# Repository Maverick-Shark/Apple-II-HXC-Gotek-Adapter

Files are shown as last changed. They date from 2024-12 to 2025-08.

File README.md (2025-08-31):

### Source

https://github.com/liveboxandy/Gotek-Rotary-Encoder

###  Description

Simple adapter PCB based on the wiring diagram from https://hxc2001.com/docs/gotek-floppy-emulator-hxc-firmware/pages/apple.html

### BOM

[Interactive BOM](https://djtersteegc.github.io/Apple-II-HXC-Gotek-Adapter/ibom.html)

| Item | Qty  | Notes | Link |
| --- | ---- | --- | --- |
| 2x17 34p 2.54mm Female Pin Socket | 1 | | [AliExpress](https://www.aliexpress.us/item/3256805948524386.html) |
| 2x10 20p 2.54mm IDC Male Box Header | 1 | | [AliExpress](https://www.aliexpress.us/item/3256807284267150.html) |
| 1x4 4p 2.54mm Female Pin Socket | 1 | | [AliExpress](https://www.aliexpress.us/item/2255800509919410.html) |
| Female Dupont Jumper Wires | 2 | From adapter to Gotek TX/RX headers | [AliExpress](https://www.aliexpress.us/item/3256807188673626.html) |
| 1x40 2.54mm Male Header | 1 | To populate Gotek header pins | [AliExpress](https://www.aliexpress.us/item/3256805949945647.html) |

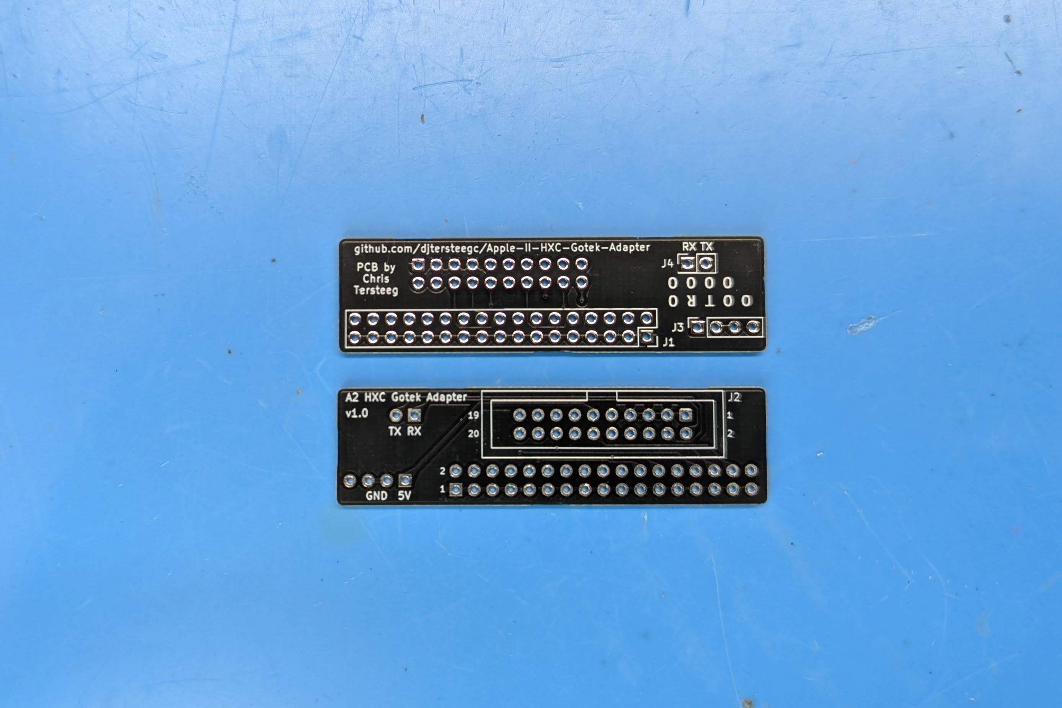
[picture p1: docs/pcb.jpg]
pcb


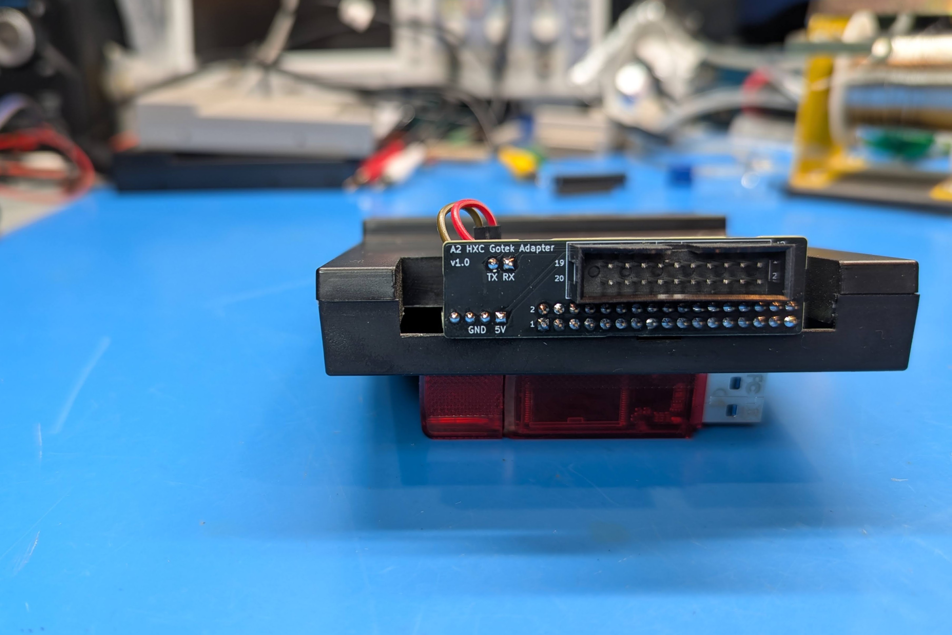
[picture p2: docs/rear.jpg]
rear


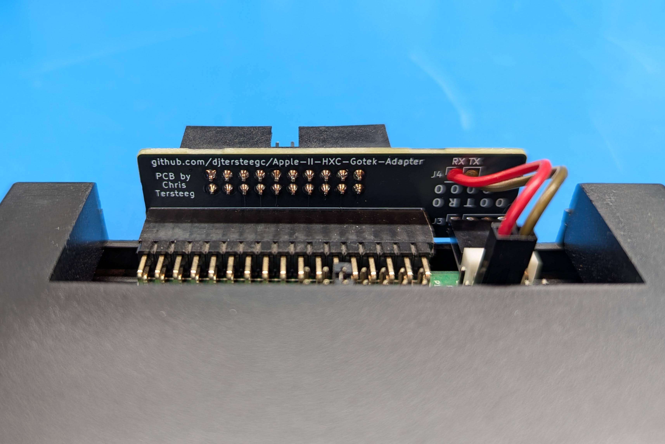
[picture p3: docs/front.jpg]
front


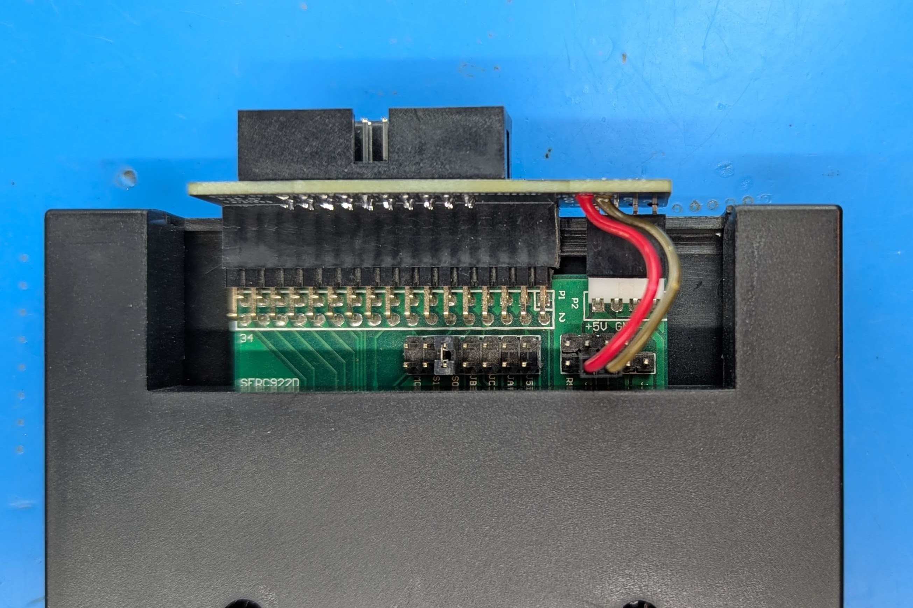
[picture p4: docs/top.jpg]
top


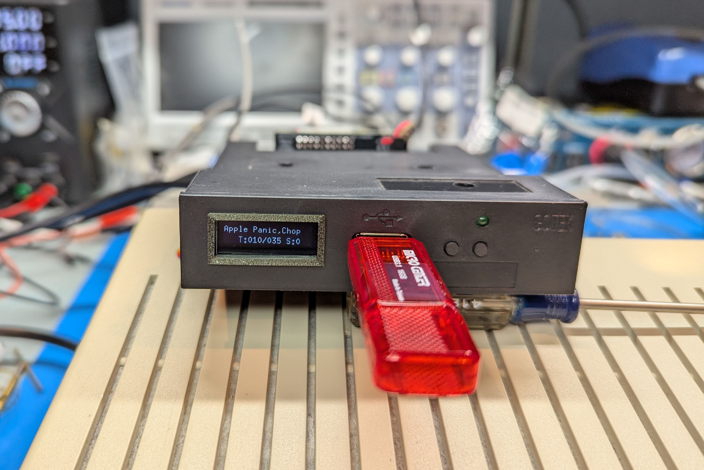
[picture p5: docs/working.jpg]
working


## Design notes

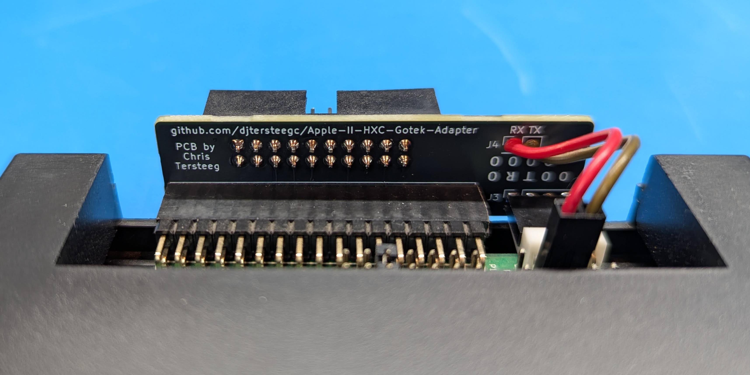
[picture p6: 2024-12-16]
docs/social.jpg

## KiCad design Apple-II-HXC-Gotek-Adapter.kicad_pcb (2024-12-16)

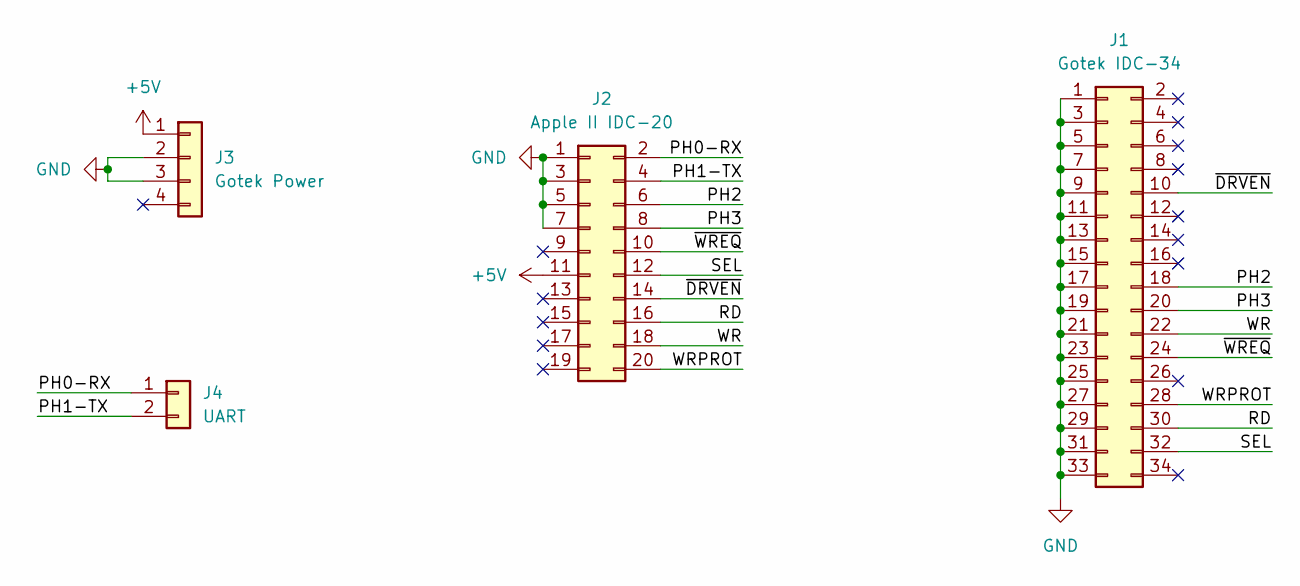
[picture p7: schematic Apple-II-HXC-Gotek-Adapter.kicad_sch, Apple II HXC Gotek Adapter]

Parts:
J1: Gotek IDC-34; PinSocket_2x17_P2.54mm_Vertical
J2: Apple II IDC-20; IDC-Header_2x10_P2.54mm_Vertical
J3: Gotek Power; PinSocket_1x04_P2.54mm_Vertical
J4: UART; PinHeader_2x01_P2.54mm_Vertical

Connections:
+5V: J2.11, J3.1
/PH0-RX: J2.2, J4.1
/PH1-TX: J2.4, J4.2
/PH2: J1.18, J2.6
/PH3: J1.20, J2.8
/RD: J1.30, J2.16
/SEL: J1.32, J2.12
/WR: J1.22, J2.18
/WRPROT: J1.28, J2.20
/~DRVEN: J1.10, J2.14
/~WREQ: J1.24, J2.10
GND: J1.1, J1.3, J1.5, J1.7, J1.9, J1.11, J1.13, J1.15, J1.17, J1.19, J1.21, J1.23, J1.25, J1.27, J1.29, J1.31, J1.33, J2.1, J2.3, J2.5, J2.7, J3.2, J3.3

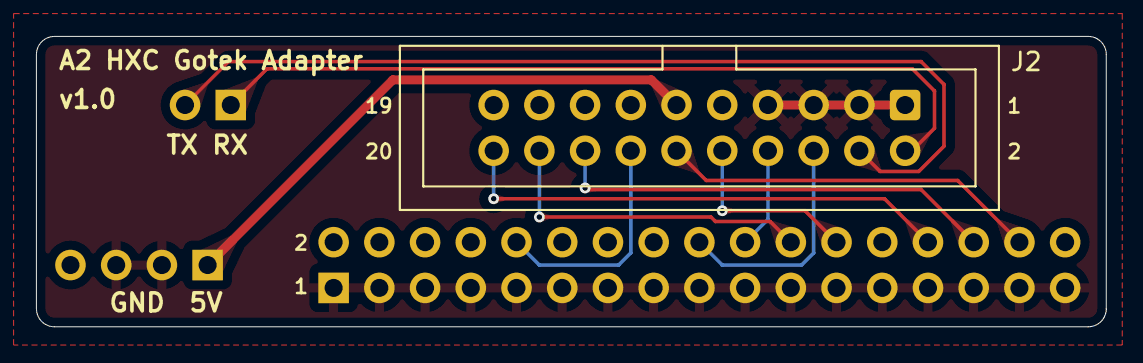
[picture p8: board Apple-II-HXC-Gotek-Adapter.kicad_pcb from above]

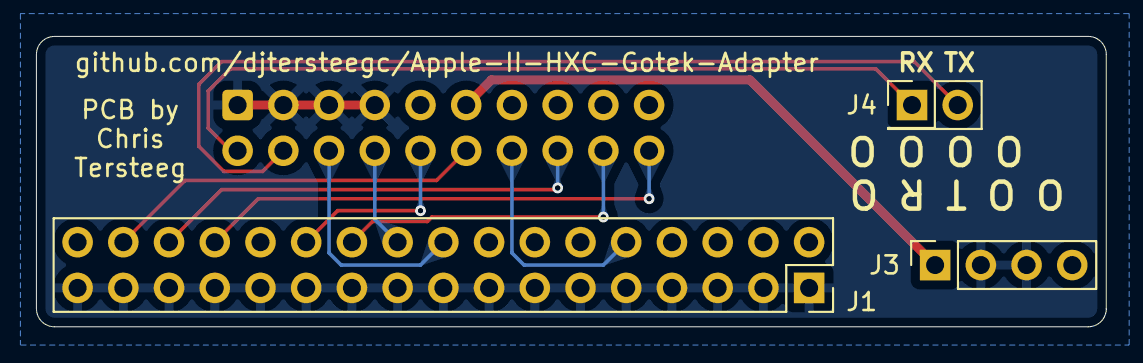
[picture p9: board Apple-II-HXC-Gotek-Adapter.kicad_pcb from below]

Board: 2 copper layers, 59.4 x 16.1 mm, 4 parts (3 on the bottom side), 12 nets.
